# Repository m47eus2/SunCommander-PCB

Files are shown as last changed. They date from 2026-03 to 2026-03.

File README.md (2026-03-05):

# SunCommander-PCB

PCB boards for energy optimalization device. Contactors control for power switching with full optical isolation. Multiple current measurments made with current transformers.

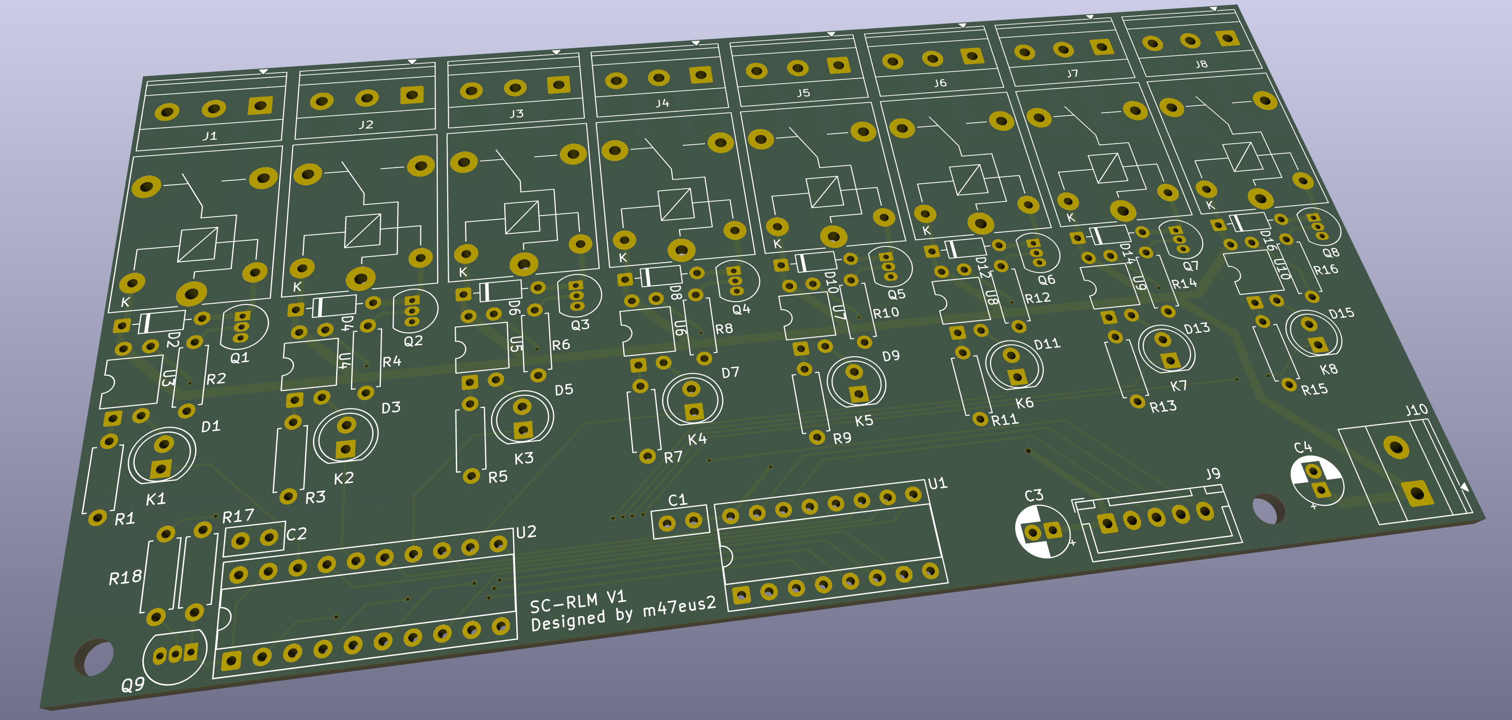
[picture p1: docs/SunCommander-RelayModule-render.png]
Relay Module PCB

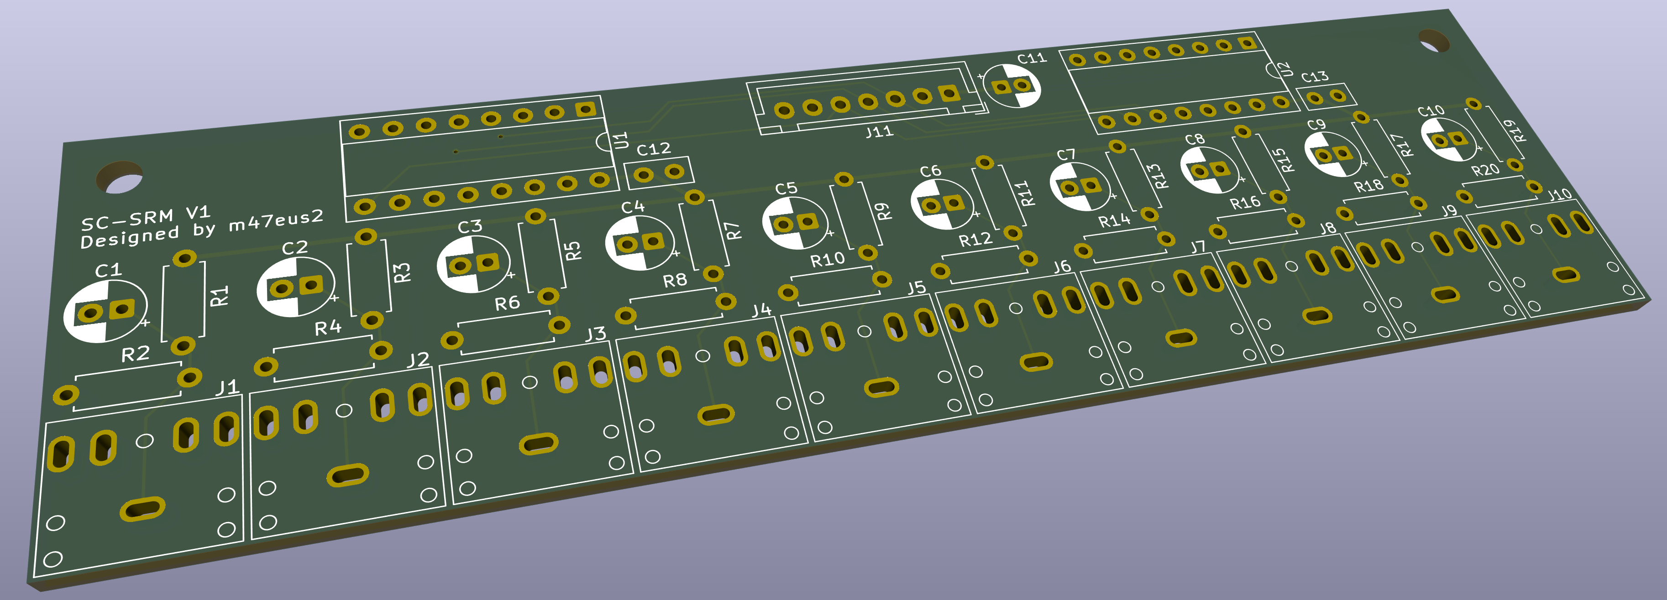
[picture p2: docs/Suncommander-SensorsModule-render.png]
Sensors Module PCB


## Relay Module
Complete 8 relay module (230V 10A) controlled by I2C with full optical isolation and separate power source for relays coils
- Relay control with full optical isolation (with PC817 optocouplers), separate power sources and LED signalization
- Optocouplers controled by I2C pin expanders (PCF8574N) and inverting digital buffers beetween
- Conntcts to MCU with power supply, I2C bus and buffer enable signal. Requires separate 5V power supply for relays coils control
- High current terminal blocks

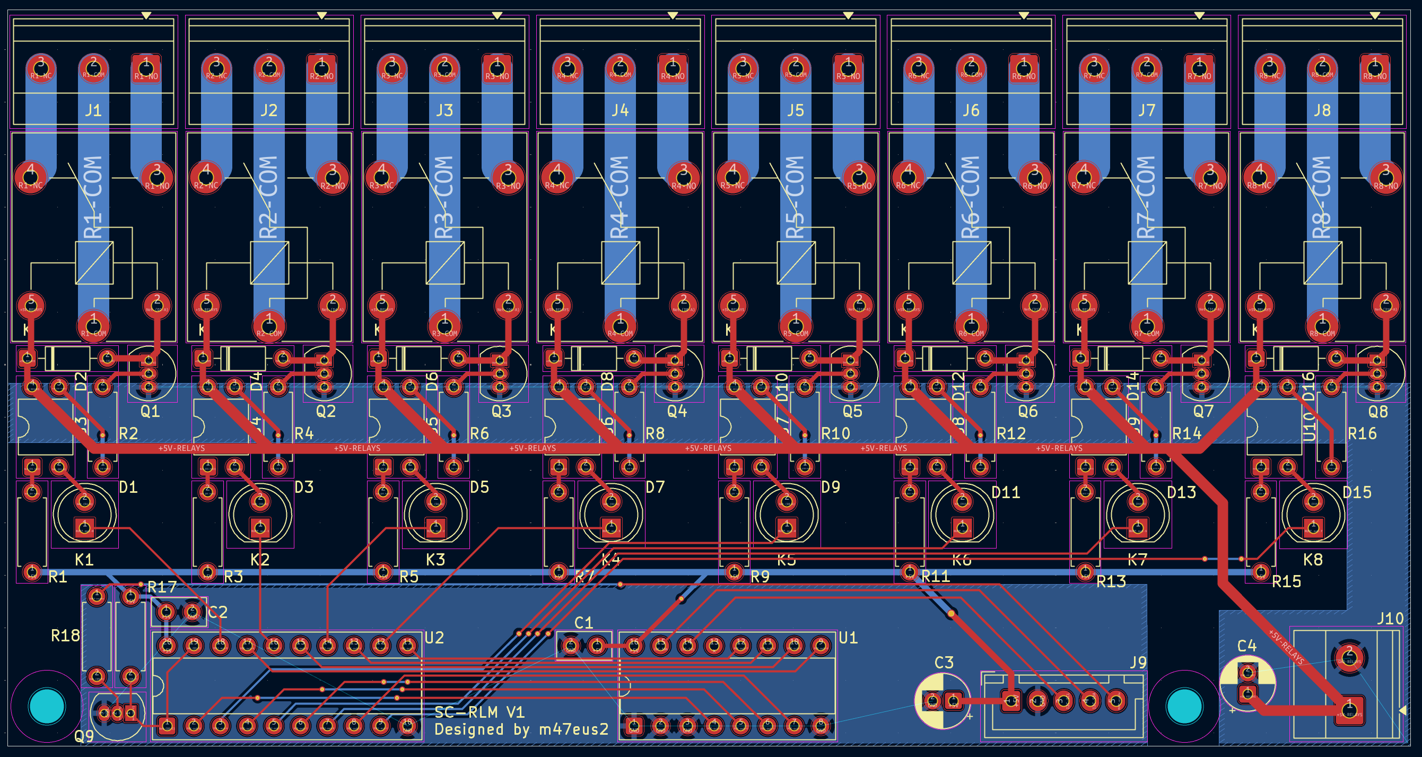
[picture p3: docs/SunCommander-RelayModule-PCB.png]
Relay Module PCB Layout

Relay Module electronic diagram

## Sensor Module
Helps measuring currents from 10 current transformers
- Connects to MCU with power supply, multiplexers address pins and 2 analog signals from 2 out of 10 choosen current sensors
- Muxing signals from each sensor by two CD4051 analog multiplexers to MCU
- Creates biases for current measurments
- Current transformers jack 3.5mm sockets with custom footprints

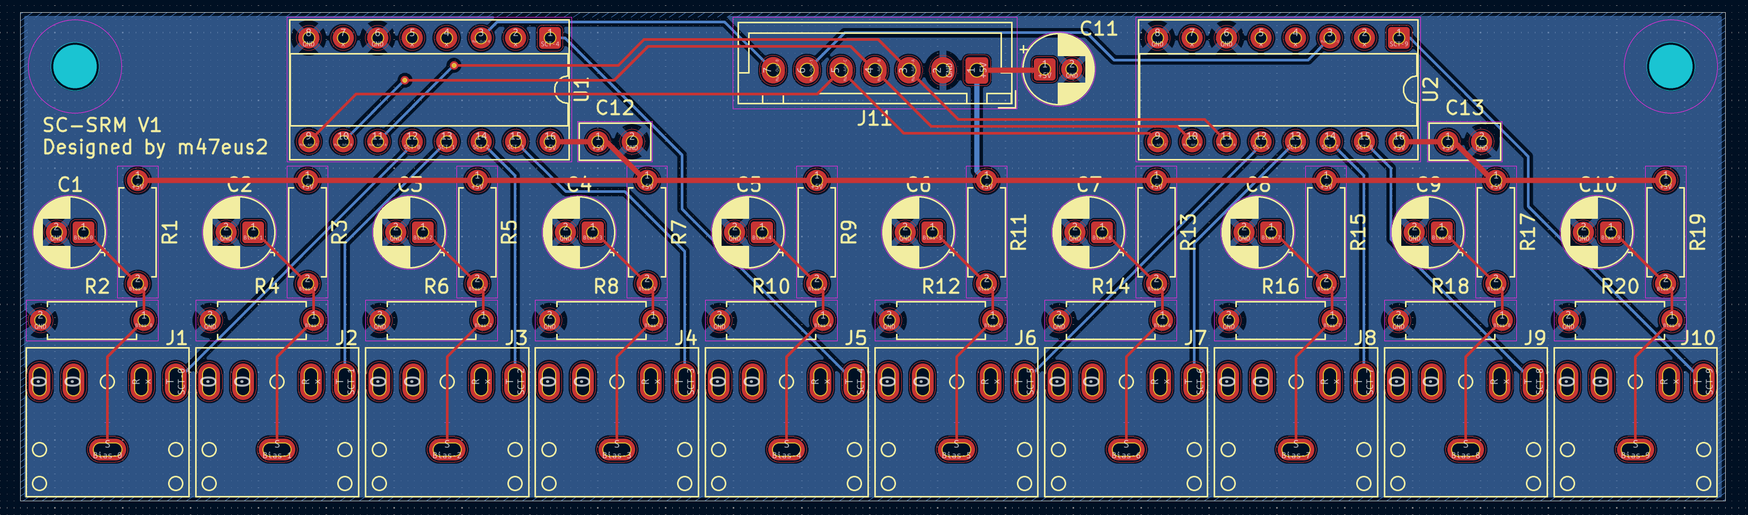
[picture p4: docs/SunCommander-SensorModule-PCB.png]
Sensors Module PCB Layout

Sensors Module electronic diagram

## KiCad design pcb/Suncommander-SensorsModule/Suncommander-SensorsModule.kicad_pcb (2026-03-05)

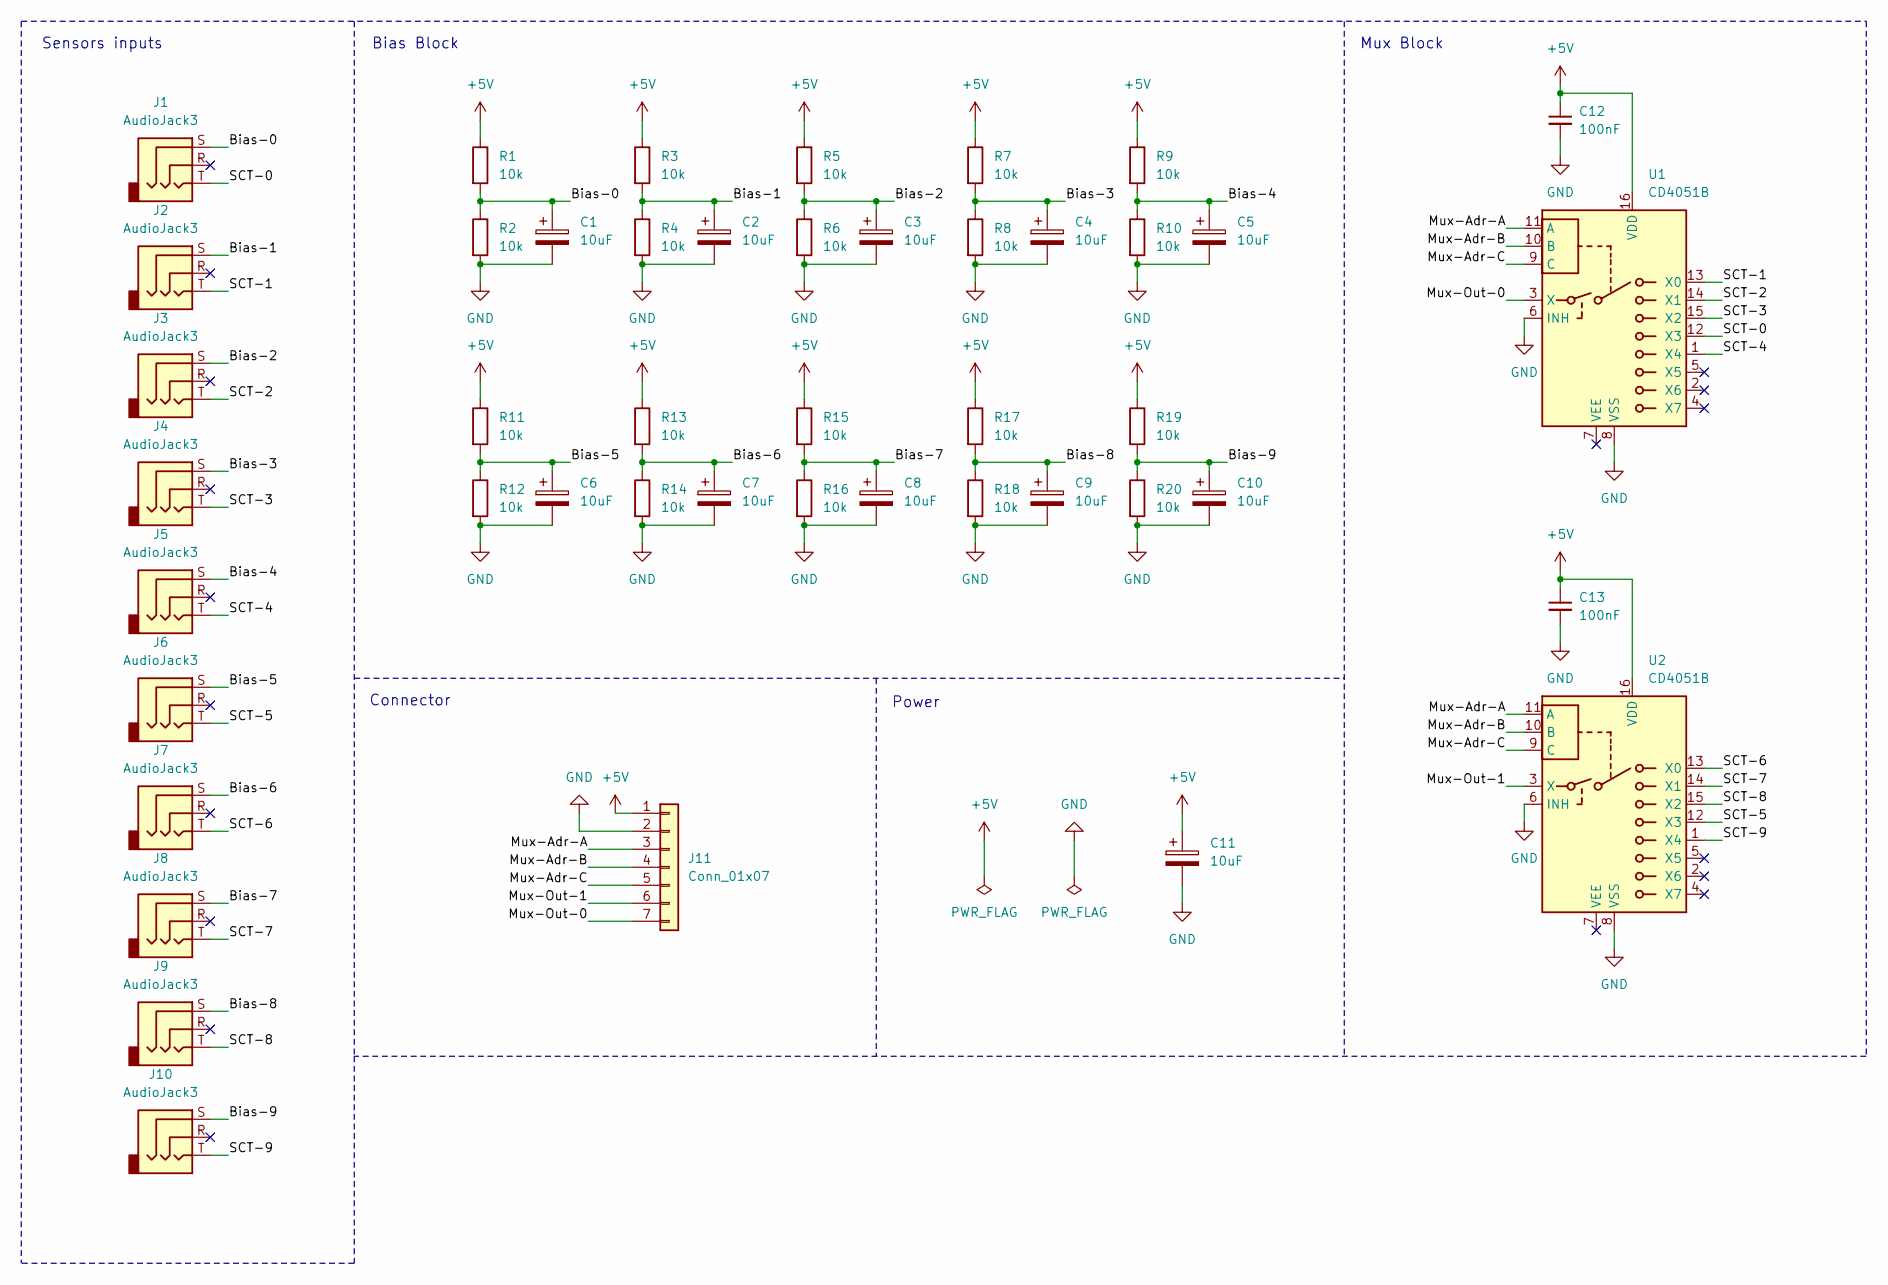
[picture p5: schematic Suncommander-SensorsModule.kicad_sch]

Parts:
C1, C2, C3, C4, C5, C6, C7, C8, C9, C10, C11: 10uF; CP_Radial_D5.0mm_P2.00mm
C12, C13: 100nF; C_Disc_D5.0mm_W2.5mm_P2.50mm
J1, J2, J3, J4, J5, J6, J7, J8, J9, J10: AudioJack3; JC-128
J11: Conn_01x07; JST_XH_B7B-XH-A_1x07_P2.50mm_Vertical
R1, R2, R3, R4, R5, R6, R7, R8, R9, R10, R11, R12, R13, R14, R15, R16, R17, R18, R19, R20: 10k; R_Axial_DIN0207_L6.3mm_D2.5mm_P7.62mm_Horizontal
U1, U2: CD4051B; DIP-16_W7.62mm_Socket

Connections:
+5V: C11.1, C12.1, C13.1, J11.1, R1.1, R3.1, R5.1, R7.1, R9.1, R11.1, R13.1, R15.1, R17.1, R19.1, U1.16 (VDD), U2.16 (VDD)
/Bias-0: C1.1, J1.S, R1.2, R2.1
/Bias-1: C2.1, J2.S, R3.2, R4.1
/Bias-2: C3.1, J3.S, R5.2, R6.1
/Bias-3: C4.1, J4.S, R7.2, R8.1
/Bias-4: C5.1, J5.S, R9.2, R10.1
/Bias-5: C6.1, J6.S, R11.2, R12.1
/Bias-6: C7.1, J7.S, R13.2, R14.1
/Bias-7: C8.1, J8.S, R15.2, R16.1
/Bias-8: C9.1, J9.S, R17.2, R18.1
/Bias-9: C10.1, J10.S, R19.2, R20.1
/Mux-Adr-A: J11.3, U1.11 (A), U2.11 (A)
/Mux-Adr-B: J11.4, U1.10 (B), U2.10 (B)
/Mux-Adr-C: J11.5, U1.9 (C), U2.9 (C)
/Mux-Out-0: J11.7, U1.3 (X)
/Mux-Out-1: J11.6, U2.3 (X)
/SCT-0: J1.T, U1.12 (X3)
/SCT-1: J2.T, U1.13 (X0)
/SCT-2: J3.T, U1.14 (X1)
/SCT-3: J4.T, U1.15 (X2)
/SCT-4: J5.T, U1.1 (X4)
/SCT-5: J6.T, U2.12 (X3)
/SCT-6: J7.T, U2.13 (X0)
/SCT-7: J8.T, U2.14 (X1)
/SCT-8: J9.T, U2.15 (X2)
/SCT-9: J10.T, U2.1 (X4)
GND: C1.2, C2.2, C3.2, C4.2, C5.2, C6.2, C7.2, C8.2, C9.2, C10.2, C11.2, C12.2, C13.2, J11.2, R2.2, R4.2, R6.2, R8.2, R10.2, R12.2, R14.2, R16.2, R18.2, R20.2, U1.6 (INH), U1.8 (VSS), U2.6 (INH), U2.8 (VSS)

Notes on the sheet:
Power
Connector
Sensors inputs
Mux Block
Bias Block

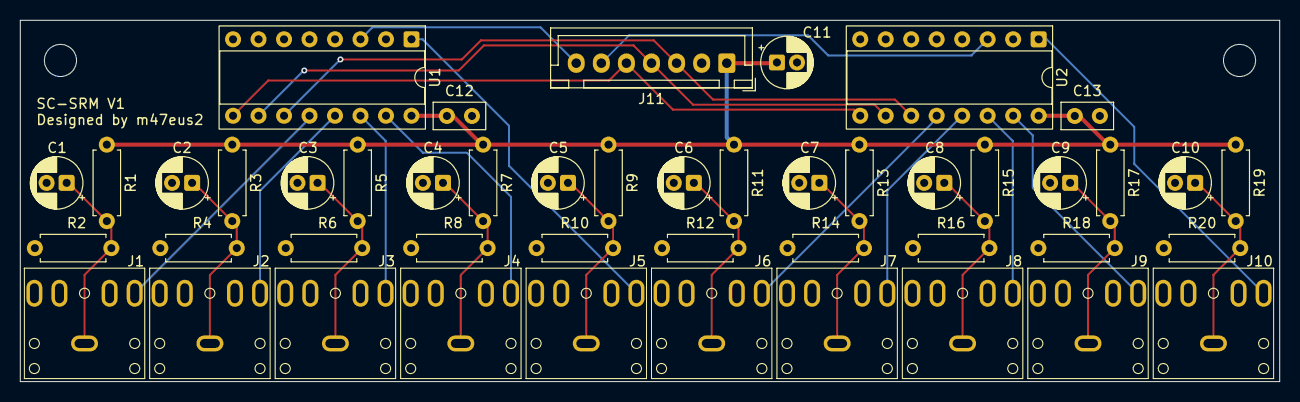
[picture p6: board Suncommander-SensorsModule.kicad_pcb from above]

Board: 2 copper layers, 125.5 x 36.0 mm, 46 parts (0 on the bottom side), 27 nets.

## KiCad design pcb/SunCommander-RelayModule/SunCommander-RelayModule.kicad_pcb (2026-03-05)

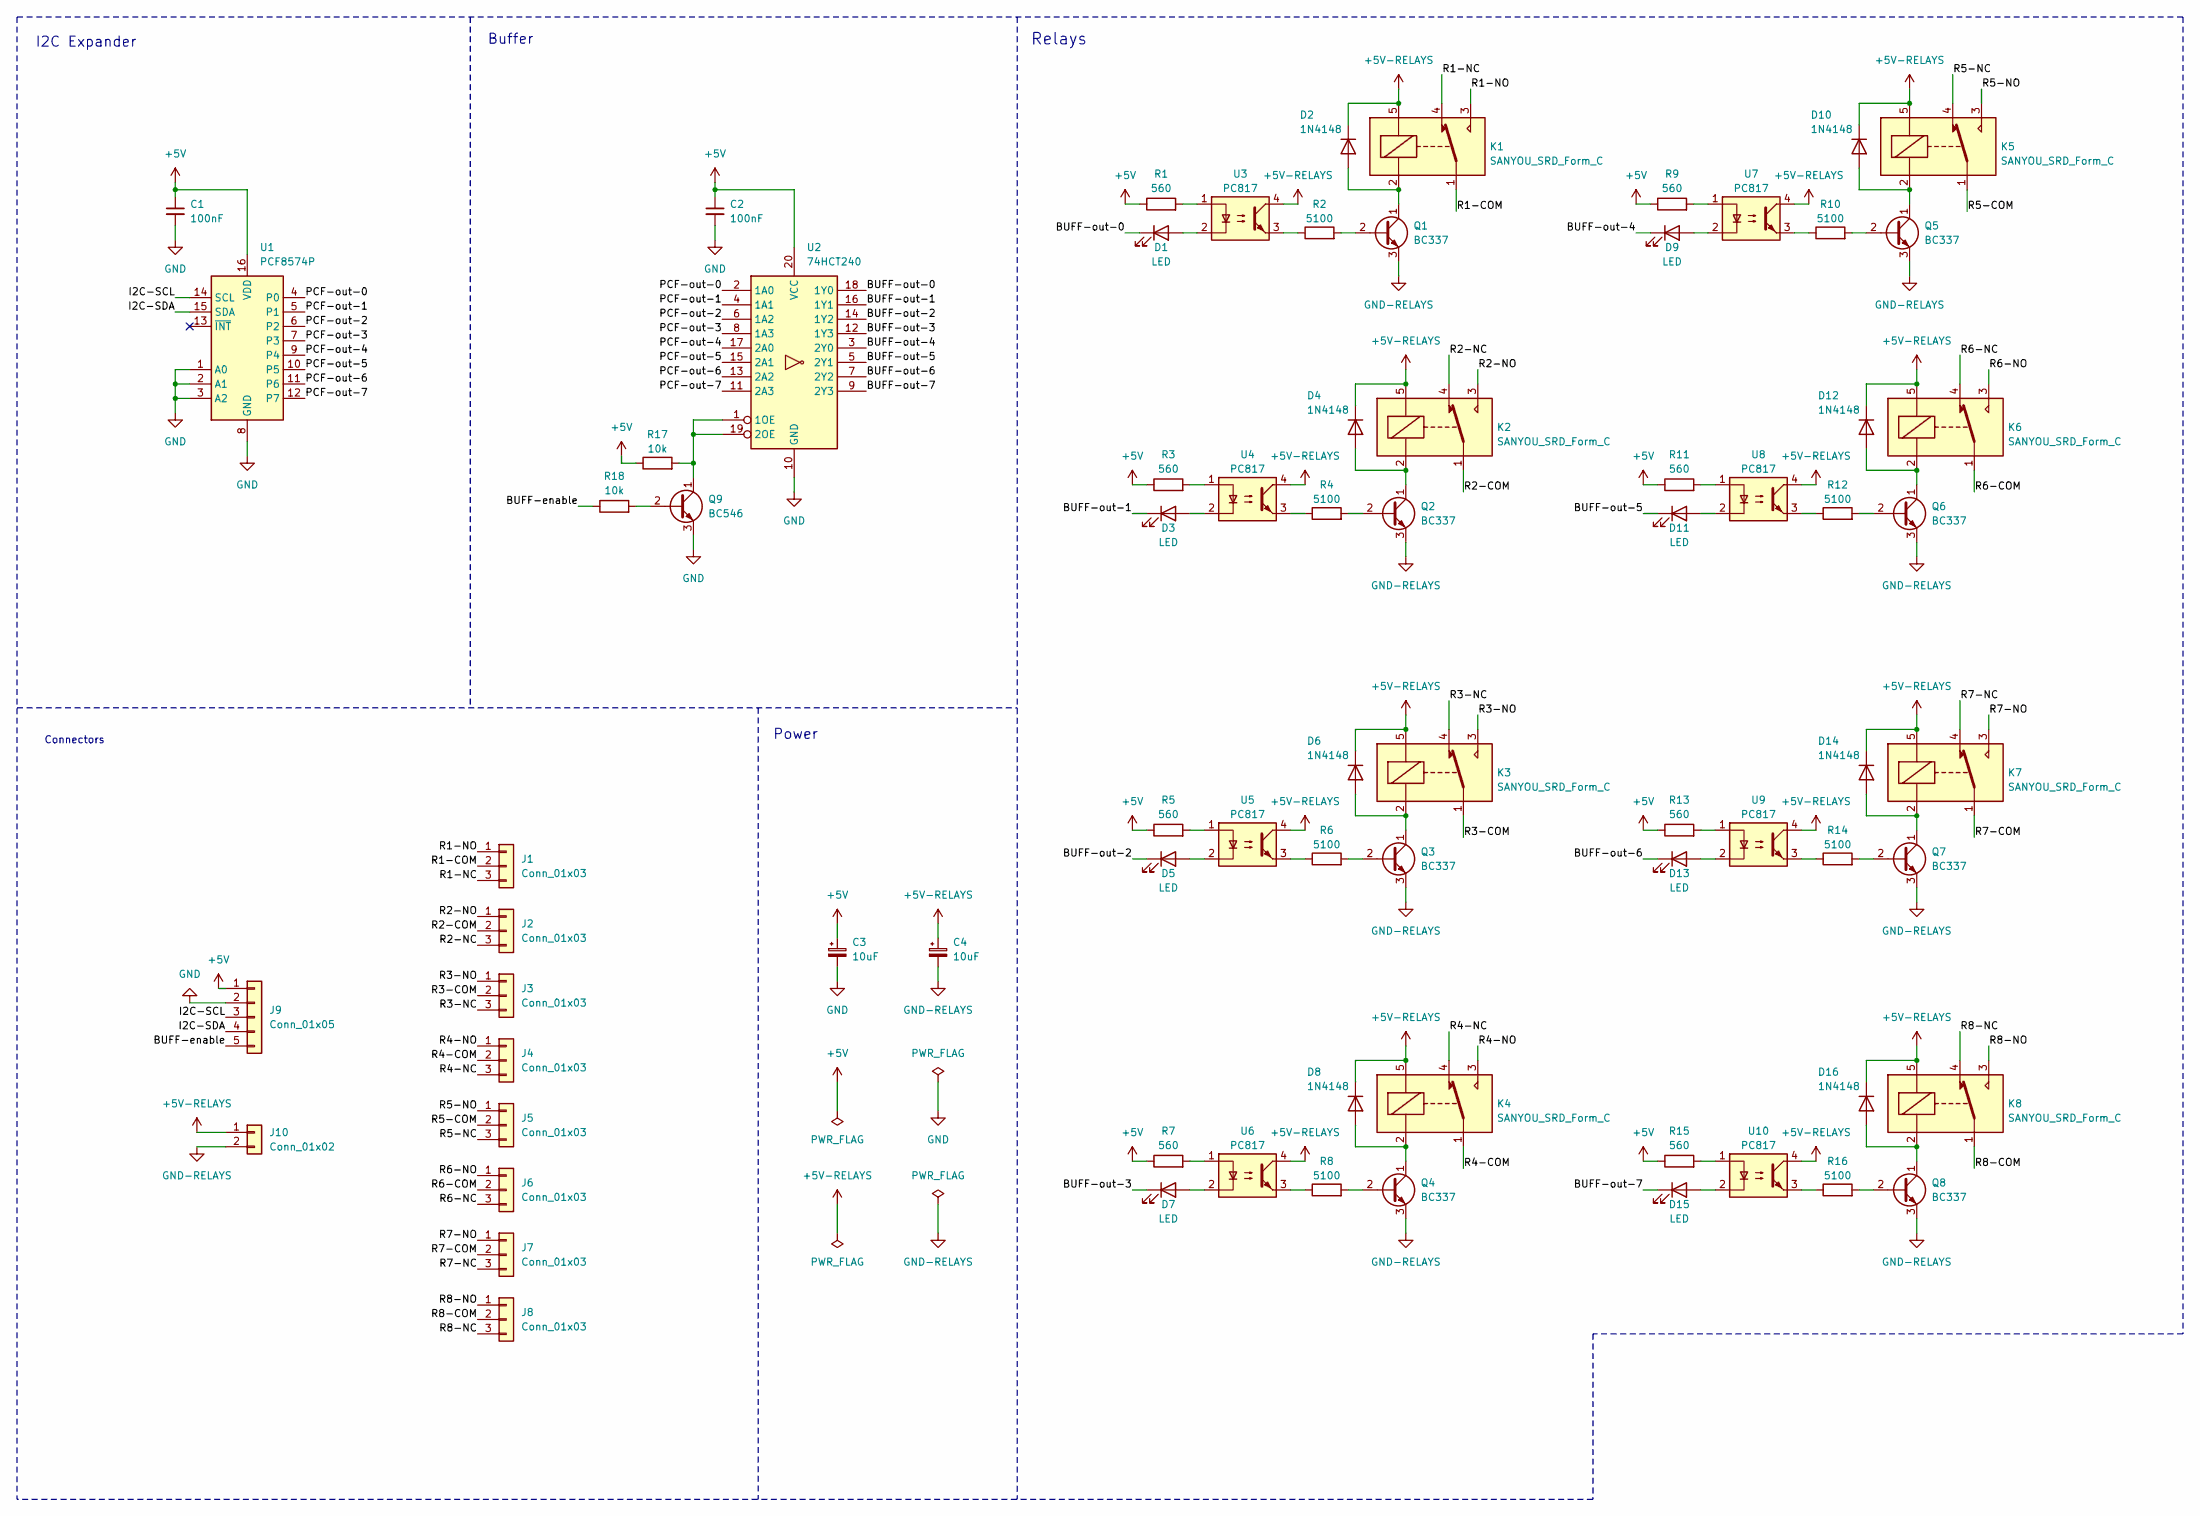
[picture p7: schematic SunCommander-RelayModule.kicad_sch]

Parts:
C1, C2: 100nF; C_Disc_D5.0mm_W2.5mm_P2.50mm
C3, C4: 10uF; CP_Radial_D5.0mm_P2.00mm
D1, D3, D5, D7, D9, D11, D13, D15: LED; LED_D5.0mm
D2, D4, D6, D8, D10, D12, D14, D16: 1N4148; D_DO-35_SOD27_P7.62mm_Horizontal
J1, J2, J3, J4, J5, J6, J7, J8: Conn_01x03; TerminalBlock_Phoenix_MKDS-1,5-3_1x03_P5.00mm_Horizontal
J9: Conn_01x05; JST_XH_B5B-XH-A_1x05_P2.50mm_Vertical
J10: Conn_01x02; TerminalBlock_Phoenix_MKDS-1,5-2_1x02_P5.00mm_Horizontal
K1, K2, K3, K4, K5, K6, K7, K8: SANYOU_SRD_Form_C; Relay_SPDT_SANYOU_SRD_Series_Form_C
Q1, Q2, Q3, Q4, Q5, Q6, Q7, Q8: BC337; TO-92_Inline-customPads
Q9: BC546; TO-92_Inline-customPads
R1, R3, R5, R7, R9, R11, R13, R15: 560; R_Axial_DIN0207_L6.3mm_D2.5mm_P7.62mm_Horizontal
R2, R4, R6, R8, R10, R12, R14, R16: 5100; R_Axial_DIN0207_L6.3mm_D2.5mm_P7.62mm_Horizontal
R17, R18: 10k; R_Axial_DIN0207_L6.3mm_D2.5mm_P7.62mm_Horizontal
U1: PCF8574P; DIP-16_W7.62mm_Socket
U2: 74HCT240; DIP-20_W7.62mm_Socket
U3, U4, U5, U6, U7, U8, U9, U10: PC817; DIP-4_W7.62mm

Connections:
+5V: C1.1, C2.1, C3.1, J9.1, R1.1, R3.1, R5.1, R7.1, R9.1, R11.1, R13.1, R15.1, R17.1, U1.16 (VDD), U2.20 (VCC)
+5V-RELAYS: C4.1, D2.1 (K), D4.1 (K), D6.1 (K), D8.1 (K), D10.1 (K), D12.1 (K), D14.1 (K), D16.1 (K), J10.1, K1.5, K2.5, K3.5, K4.5, K5.5, K6.5, K7.5, K8.5, U3.4, U4.4, U5.4, U6.4, U7.4, U8.4, U9.4, U10.4
/BUFF-enable: J9.5, R18.1
/BUFF-out-0: D1.1 (K), U2.18 (1Y0)
/BUFF-out-1: D3.1 (K), U2.16 (1Y1)
/BUFF-out-2: D5.1 (K), U2.14 (1Y2)
/BUFF-out-3: D7.1 (K), U2.12 (1Y3)
/BUFF-out-4: D9.1 (K), U2.3 (2Y0)
/BUFF-out-5: D11.1 (K), U2.5 (2Y1)
/BUFF-out-6: D13.1 (K), U2.7 (2Y2)
/BUFF-out-7: D15.1 (K), U2.9 (2Y3)
/I2C-SCL: J9.3, U1.14 (SCL)
/I2C-SDA: J9.4, U1.15 (SDA)
/PCF-out-0: U1.4 (P0), U2.2 (1A0)
/PCF-out-1: U1.5 (P1), U2.4 (1A1)
/PCF-out-2: U1.6 (P2), U2.6 (1A2)
/PCF-out-3: U1.7 (P3), U2.8 (1A3)
/PCF-out-4: U1.9 (P4), U2.17 (2A0)
/PCF-out-5: U1.10 (P5), U2.15 (2A1)
/PCF-out-6: U1.11 (P6), U2.13 (2A2)
/PCF-out-7: U1.12 (P7), U2.11 (2A3)
/R1-COM: J1.2, K1.1
/R1-NC: J1.3, K1.4
/R1-NO: J1.1, K1.3
/R2-COM: J2.2, K2.1
/R2-NC: J2.3, K2.4
/R2-NO: J2.1, K2.3
/R3-COM: J3.2, K3.1
/R3-NC: J3.3, K3.4
/R3-NO: J3.1, K3.3
/R4-COM: J4.2, K4.1
/R4-NC: J4.3, K4.4
/R4-NO: J4.1, K4.3
/R5-COM: J5.2, K5.1
/R5-NC: J5.3, K5.4
/R5-NO: J5.1, K5.3
/R6-COM: J6.2, K6.1
/R6-NC: J6.3, K6.4
/R6-NO: J6.1, K6.3
/R7-COM: J7.2, K7.1
/R7-NC: J7.3, K7.4
/R7-NO: J7.1, K7.3
/R8-COM: J8.2, K8.1
/R8-NC: J8.3, K8.4
/R8-NO: J8.1, K8.3
GND: C1.2, C2.2, C3.2, J9.2, Q9.3 (E), U1.1 (A0), U1.2 (A1), U1.3 (A2), U1.8 (GND), U2.10 (GND)
GND-RELAYS: C4.2, J10.2, Q1.3 (E), Q2.3 (E), Q3.3 (E), Q4.3 (E), Q5.3 (E), Q6.3 (E), Q7.3 (E), Q8.3 (E)
unnamed: D1.2 (A), U3.2
unnamed: D2.2 (A), K1.2, Q1.1 (C)
unnamed: D3.2 (A), U4.2
unnamed: D4.2 (A), K2.2, Q2.1 (C)
unnamed: D5.2 (A), U5.2
unnamed: D6.2 (A), K3.2, Q3.1 (C)
unnamed: D7.2 (A), U6.2
unnamed: D8.2 (A), K4.2, Q4.1 (C)
unnamed: D9.2 (A), U7.2
unnamed: D10.2 (A), K5.2, Q5.1 (C)
unnamed: D11.2 (A), U8.2
unnamed: D12.2 (A), K6.2, Q6.1 (C)
unnamed: D13.2 (A), U9.2
unnamed: D14.2 (A), K7.2, Q7.1 (C)
unnamed: D15.2 (A), U10.2
unnamed: D16.2 (A), K8.2, Q8.1 (C)
unnamed: Q1.2 (B), R2.2
unnamed: Q2.2 (B), R4.2
unnamed: Q3.2 (B), R6.2
unnamed: Q4.2 (B), R8.2
unnamed: Q5.2 (B), R10.2
unnamed: Q6.2 (B), R12.2
unnamed: Q7.2 (B), R14.2
unnamed: Q8.2 (B), R16.2
unnamed: Q9.2 (B), R18.2
unnamed: Q9.1 (C), R17.2, U2.1 (1OE), U2.19 (2OE)
unnamed: R1.2, U3.1
unnamed: R2.1, U3.3
unnamed: R3.2, U4.1
unnamed: R4.1, U4.3
unnamed: R5.2, U5.1
unnamed: R6.1, U5.3
unnamed: R7.2, U6.1
unnamed: R8.1, U6.3
unnamed: R9.2, U7.1
unnamed: R10.1, U7.3
unnamed: R11.2, U8.1
unnamed: R12.1, U8.3
unnamed: R13.2, U9.1
unnamed: R14.1, U9.3
unnamed: R15.2, U10.1
unnamed: R16.1, U10.3

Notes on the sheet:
Connectors
Buffer
I2C Expander
Power
Relays

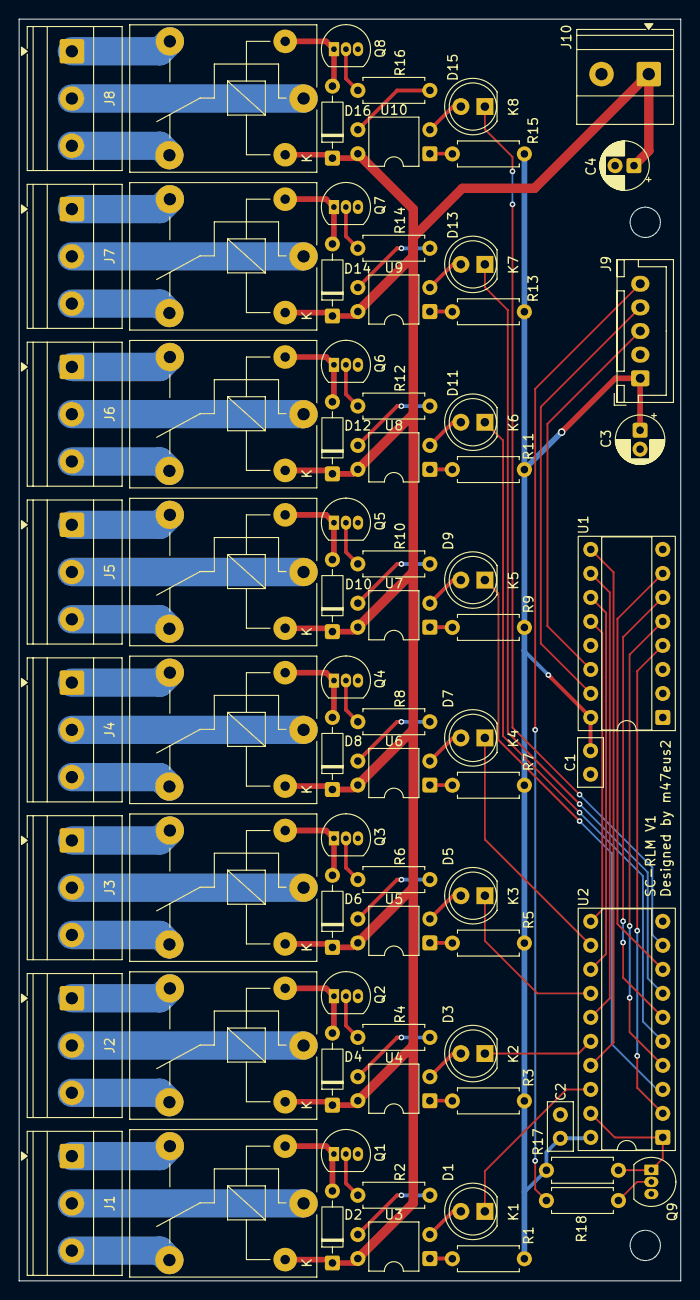
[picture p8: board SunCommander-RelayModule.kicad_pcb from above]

Board: 2 copper layers, 70.0 x 133.5 mm, 75 parts (0 on the bottom side), 89 nets.
